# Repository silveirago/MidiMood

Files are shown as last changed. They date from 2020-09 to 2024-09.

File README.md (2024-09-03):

# MidiMood

For a detailed tutorial, visit: 

- Making Music with Arduino: https://go.musiconerd.com/making-music-with-arduino
- Curso Fazendo Música com Arduino em Português: https://go.musiconerd.com/curso-completo
- Build process video: https://youtu.be/aLhOO-UiMg4

This repository contains the code for a custom MIDI controller project called MidiMood, built using an ATmega32U4 microcontroller (or similar). The project is designed to handle potentiometers, buttons, and other controls to send MIDI messages via USB, BLE, or standard MIDI protocols.

## Table of Contents

- [Overview](#overview)
- [Features](#features)
- [Files Description](#files-description)
- [Setup Instructions](#setup-instructions)
- [Dependencies](#dependencies)
- [Usage](#usage)
- [License](#license)

## Overview

MidiMood is a comprehensive MIDI controller implementation that supports various input methods (buttons, potentiometers, encoders) and output methods (USB MIDI, BLE MIDI). The controller is designed to be highly customizable, supporting multiple microcontroller platforms including ATmega32U4, ATmega328, and Teensy.

## Features

- **USB MIDI Support**: Send and receive MIDI messages over USB.
- **BLE MIDI Support**: Use Bluetooth Low Energy (BLE) for wireless MIDI communication.
- **Potentiometer and Button Handling**: Capture input from potentiometers and buttons and convert them into MIDI messages.
- **Multiplexer Support**: Extend the number of inputs using multiplexers.
- **Debugging Support**: Debugging messages can be enabled via serial communication.
- **Multi-platform**: Supports ATmega32U4, ATmega328, and Teensy microcontrollers.

## Files Description

- **_MidiMood.ino**: The main Arduino sketch that initializes the MIDI controller and runs the main loop.
- **A_POTENTIOMETERS.ino**: Contains the logic for reading potentiometer values and converting them into MIDI Control Change messages.
- **B_BUTTONS.ino**: Handles the button inputs, converting them into MIDI Note On/Off or Control Change messages.
- **FUNCTIONS.ino**: Helper functions used throughout the project, including handling MIDI messages and other utility functions.
- **LOOP.ino**: The main loop where the program checks for inputs and sends out MIDI messages.
- **MACKIE.h**: Defines constants for Mackie Control Universal (MCU) protocol, used for controlling DAWs.
- **Z_ATMEGA32U4.ino**: Microcontroller-specific setup code for ATmega32U4-based boards.
- **Z_SETUP.ino**: General setup code, initializing pins, and configuring input/output modes.

## Material

* Arduino Pro Micro: https://amzn.to/2Vcz3Nz
* Wires: https://amzn.to/2xugvPF
* Bare Copper Wire (optional) 18-24-gauge: https://amzn.to/2FVuDpe
* 26 Rotary potentiometer b10k: https://amzn.to/3ckRKUY
* 26 Knobs
* Spacers M3 35mm: https://amzn.to/2z15BkN
* M3 screws: https://amzn.to/2RHtfJw
* Multiplexer CD4067: https://amzn.to/303jJVe
* 11 Toggle switch: https://amzn.to/3hDmORR
* 1 led
* 1 led support
* 1 resistor 1k ohm

## Setup Instructions

### 1. Clone the Repository

```bash
git clone https://github.com/yourusername/midi-controller-project.git
cd midi-controller-project
```

### 2. Install Arduino IDE

Make sure you have the Arduino IDE installed on your computer. You can download it from the [official website](https://www.arduino.cc/en/software).

### 3. Open the Project

Open the `_MidiMood.ino` file in the Arduino IDE. This file serves as the entry point to the project.

### 4. Select Your Board

In the Arduino IDE, select the appropriate board based on your microcontroller:
- For ATmega32U4 boards (e.g., Arduino Leonardo), select **Arduino Leonardo**.
- For ATmega328 boards (e.g., Arduino Uno), select **Arduino Uno**.
- For Teensy boards, select the correct Teensy model.

### 5. Upload the Code

Connect your microcontroller to your computer via USB and upload the code using the **Upload** button in the Arduino IDE.

## Dependencies

- **ResponsiveAnalogRead**: Library for smoothing analog readings from potentiometers.
- **MIDI Library**: To handle MIDI communication over USB and serial.
- **BLE MIDI**: For Bluetooth MIDI communication (if using BLE).

You can install these libraries using the Arduino Library Manager.

## Usage

Once the code is uploaded, your MIDI controller will be recognized by your computer or mobile device as a MIDI device. You can start using it to send MIDI messages to your DAW or other MIDI-compatible software.

### Debugging

If you want to see debugging messages, enable the `DEBUG` flag in the code. This will allow you to monitor the MIDI messages and other details via the serial monitor in the Arduino IDE.

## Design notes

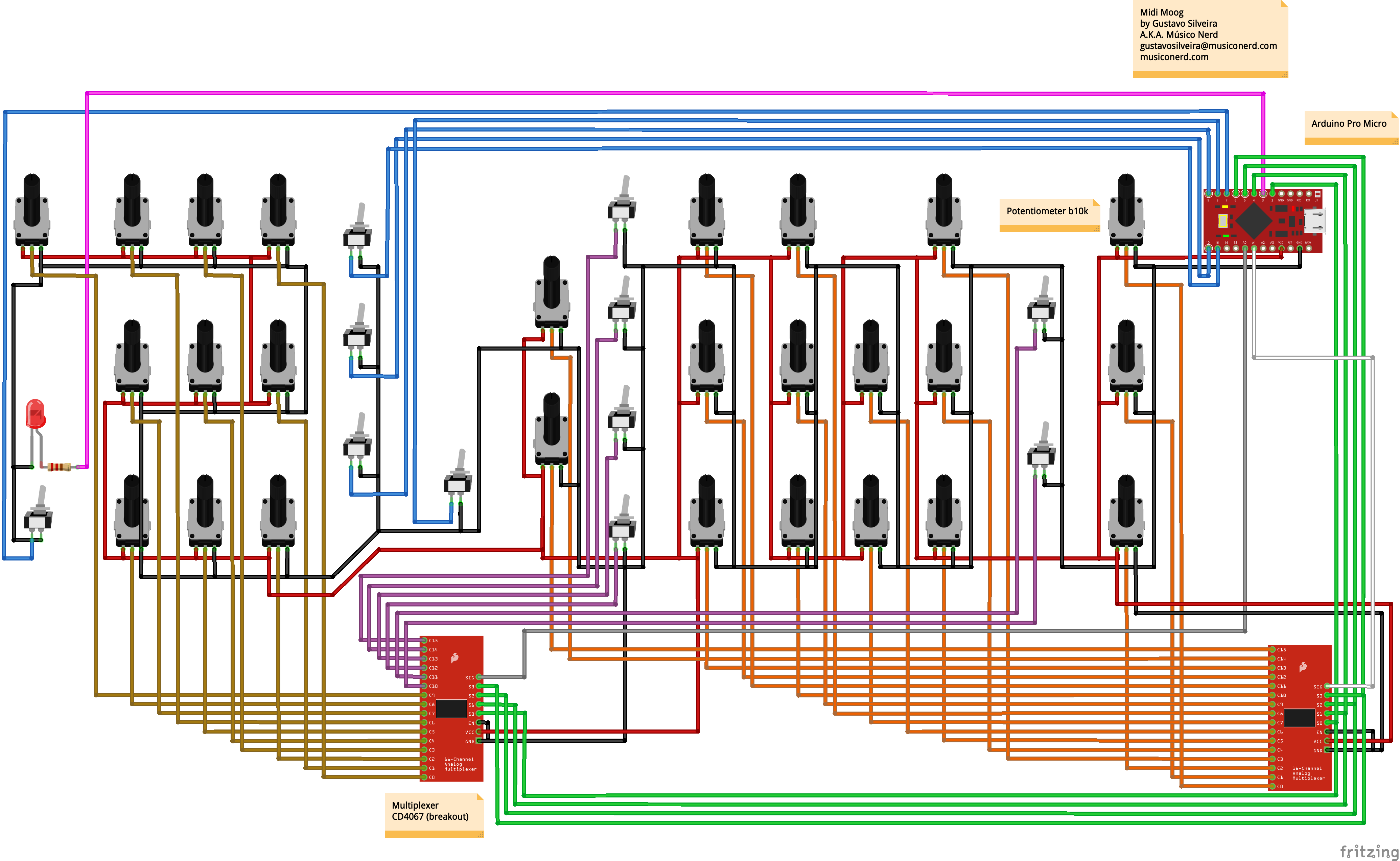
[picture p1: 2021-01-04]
Schematics/MidiMood schematic.png

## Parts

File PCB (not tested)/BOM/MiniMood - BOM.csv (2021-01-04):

Comment | Designator | Footprint | LCSC Part Number
CD74HC4067M | 4067_1,4067_2 | Package_SO:SOIC-24W_7.5x15.4mm_P1.27mm | C496123
100nF | C1,C2 | Capacitor_SMD:C_0603_1608Metric | C14663
220OHMS | R1 | Resistor_SMD:R_0603_1608Metric_Pad0.98x0.95mm_HandSolder | C21189

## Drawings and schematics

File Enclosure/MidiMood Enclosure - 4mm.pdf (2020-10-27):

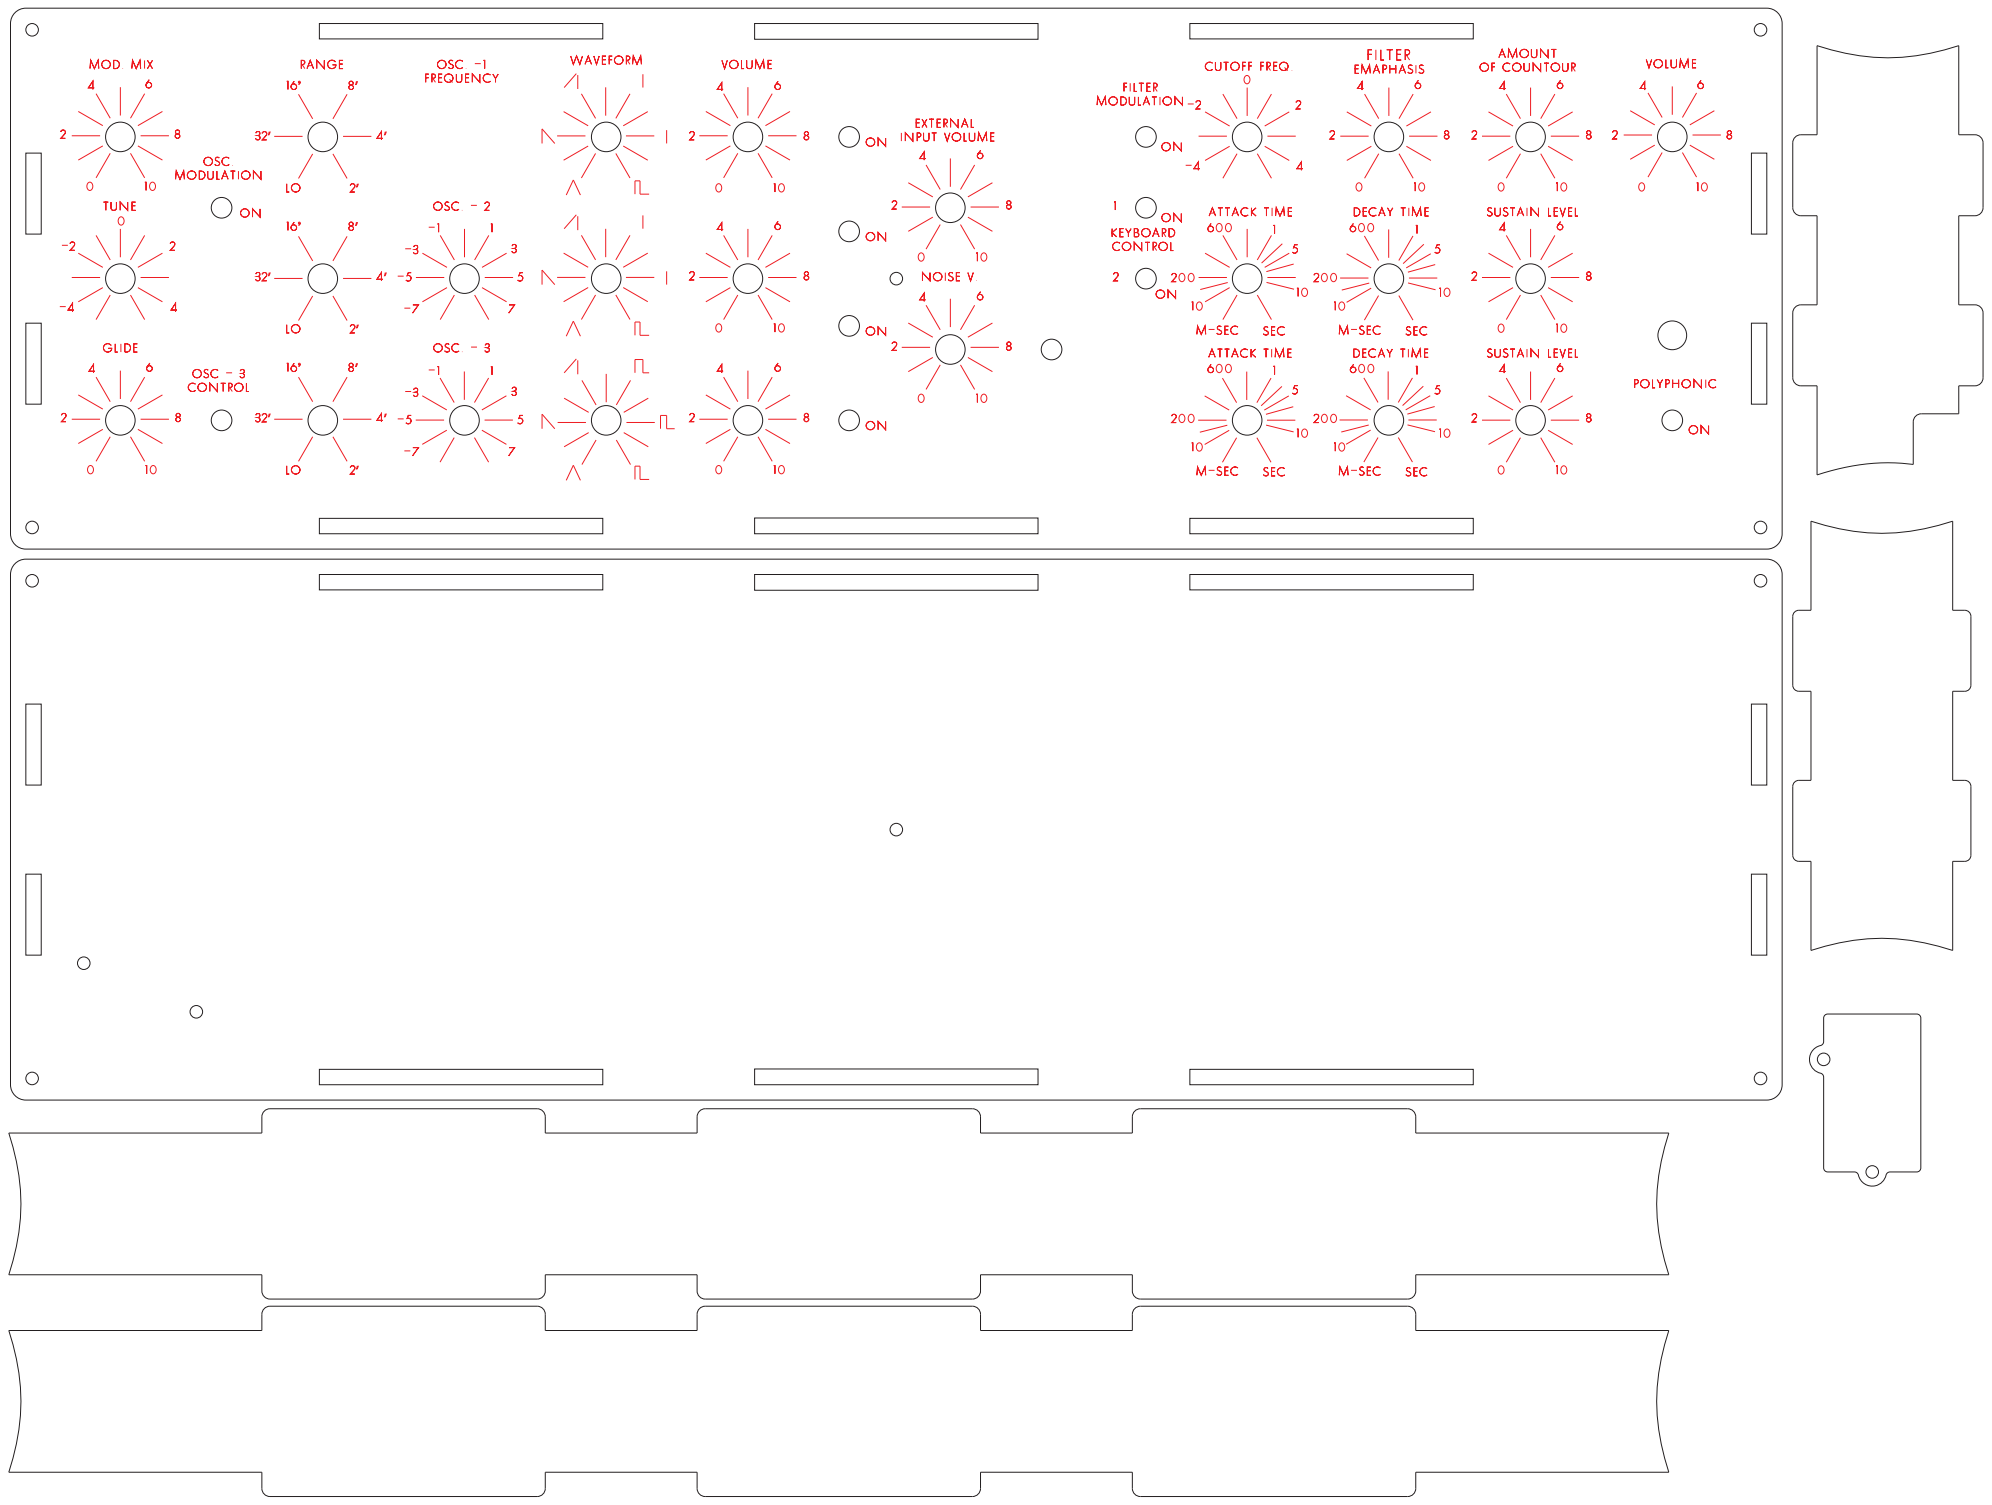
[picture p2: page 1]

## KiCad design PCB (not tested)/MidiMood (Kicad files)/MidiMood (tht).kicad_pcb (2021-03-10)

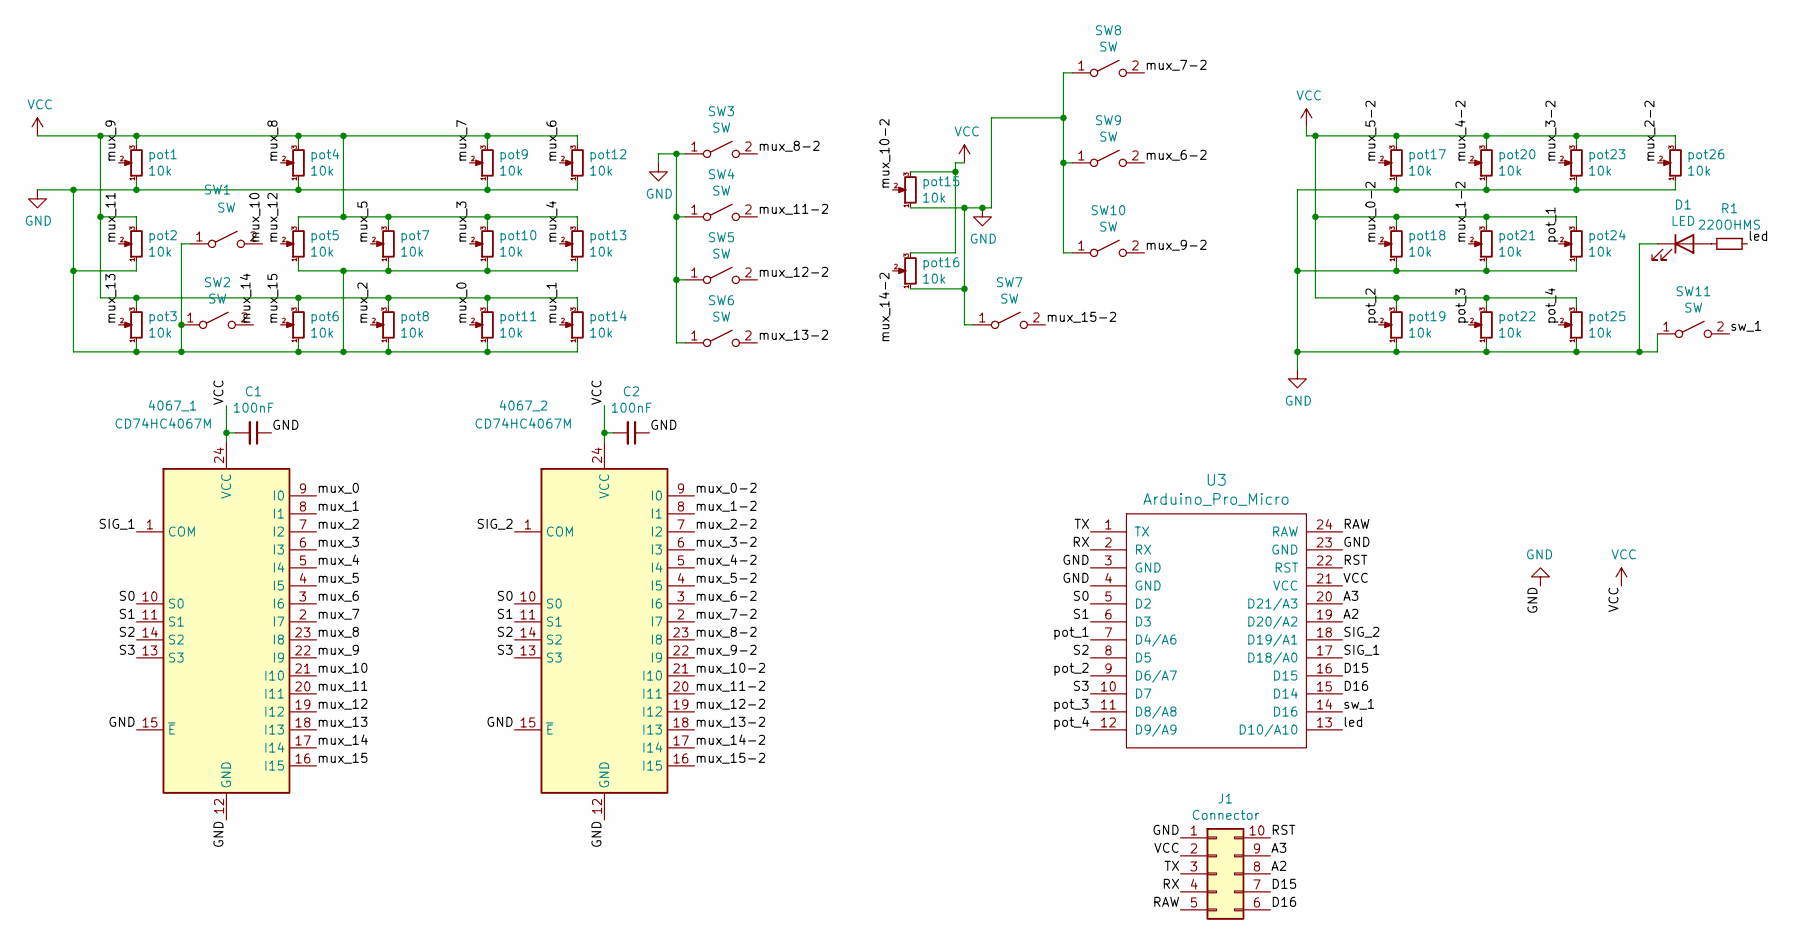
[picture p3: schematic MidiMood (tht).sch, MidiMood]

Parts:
4067_1, 4067_2: CD74HC4067M; SOIC-24W_7.5x15.4mm_P1.27mm; LCSC Part Number C496123
C1, C2: 100nF; C_Disc_D3.0mm_W1.6mm_P2.50mm; LCSC Part Number C14663
D1: LED; LED_D5.0mm
J1: Connector; PinHeader_2x05_P2.54mm_Vertical
R1: 220OHMS; R_Axial_DIN0204_L3.6mm_D1.6mm_P5.08mm_Horizontal; LCSC Part Number C21189
SW1, SW2, SW3, SW4, SW5, SW6, SW7, SW8, SW9, SW10, SW11: SW; Toggle switch small
U3: Arduino_Pro_Micro; ProMicro
pot1, pot2, pot3, pot4, pot5, pot6, pot7, pot8, pot9, pot10, pot11, pot12, pot13, pot14, pot15, pot16, pot17, pot18, pot19, pot20, pot21, pot22, pot23, pot24, pot25, pot26: 10k; Potentiometer_Alpha_RD901F-40-00D_Single_Vertical_CircularH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; LCSC RK09D1130C3C

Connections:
/A2: J1.8, U3.19 (D20/A2)
/A3: J1.9, U3.20 (D21/A3)
/D15: J1.7, U3.16 (D15)
/D16: J1.6, U3.15 (D14)
/RAW: J1.5, U3.24 (RAW)
/RST: J1.10, U3.22 (RST)
/RX: J1.4, U3.2 (RX)
/S0: 4067_1.10 (S0), 4067_2.10 (S0), U3.5 (D2)
/S1: 4067_1.11 (S1), 4067_2.11 (S1), U3.6 (D3)
/S2: 4067_1.14 (S2), 4067_2.14 (S2), U3.8 (D5)
/S3: 4067_1.13 (S3), 4067_2.13 (S3), U3.10 (D7)
/SIG_1: 4067_1.1 (COM), U3.17 (D18/A0)
/SIG_2: 4067_2.1 (COM), U3.18 (D19/A1)
/TX: J1.3, U3.1 (TX)
/led: R1.1, U3.13 (D10/A10)
/mux_0: 4067_1.9 (I0), pot11.2
/mux_0-2: 4067_2.9 (I0), pot18.2
/mux_1: 4067_1.8 (I1), pot14.2
/mux_1-2: 4067_2.8 (I1), pot21.2
/mux_2: 4067_1.7 (I2), pot8.2
/mux_2-2: 4067_2.7 (I2), pot26.2
/mux_3: 4067_1.6 (I3), pot10.2
/mux_3-2: 4067_2.6 (I3), pot23.2
/mux_4: 4067_1.5 (I4), pot13.2
/mux_4-2: 4067_2.5 (I4), pot20.2
/mux_5: 4067_1.4 (I5), pot7.2
/mux_5-2: 4067_2.4 (I5), pot17.2
/mux_6: 4067_1.3 (I6), pot12.2
/mux_6-2: 4067_2.3 (I6), SW9.2 (B)
/mux_7: 4067_1.2 (I7), pot9.2
/mux_7-2: 4067_2.2 (I7), SW8.2 (B)
/mux_8: 4067_1.23 (I8), pot4.2
/mux_8-2: 4067_2.23 (I8), SW3.2 (B)
/mux_9: 4067_1.22 (I9), pot1.2
/mux_9-2: 4067_2.22 (I9), SW10.2 (B)
/mux_10: 4067_1.21 (I10), SW1.2 (B)
/mux_10-2: 4067_2.21 (I10), pot15.2
/mux_11: 4067_1.20 (I11), pot2.2
/mux_11-2: 4067_2.20 (I11), SW4.2 (B)
/mux_12: 4067_1.19 (I12), pot5.2
/mux_12-2: 4067_2.19 (I12), SW5.2 (B)
/mux_13: 4067_1.18 (I13), pot3.2
/mux_13-2: 4067_2.18 (I13), SW6.2 (B)
/mux_14: 4067_1.17 (I14), SW2.2 (B)
/mux_14-2: 4067_2.17 (I14), pot16.2
/mux_15: 4067_1.16 (I15), pot6.2
/mux_15-2: 4067_2.16 (I15), SW7.2 (B)
/pot_1: U3.7 (D4/A6), pot24.2
/pot_2: U3.9 (D6/A7), pot19.2
/pot_3: U3.11 (D8/A8), pot22.2
/pot_4: U3.12 (D9/A9), pot25.2
/sw_1: SW11.2 (B), U3.14 (D16)
GND: 4067_1.12 (GND), 4067_1.15 (~E), 4067_2.12 (GND), 4067_2.15 (~E), C1.1, C2.1, D1.1 (K), J1.1, SW1.1 (A), SW2.1 (A), SW3.1 (A), SW4.1 (A), SW5.1 (A), SW6.1 (A), SW7.1 (A), SW8.1 (A), SW9.1 (A), SW10.1 (A), SW11.1 (A), U3.3 (GND), U3.4 (GND), U3.23 (GND), pot1.1, pot2.1, pot3.1, pot4.1, pot5.1, pot6.1, pot7.1, pot8.1, pot9.1, pot10.1, pot11.1, pot12.1, pot13.1, pot14.1, pot15.1, pot16.1, pot17.1, pot18.1, pot19.1, pot20.1, pot21.1, pot22.1, pot23.1, pot24.1, pot25.1, pot26.1
unnamed: D1.2 (A), R1.2
VCC: 4067_1.24 (VCC), 4067_2.24 (VCC), C1.2, C2.2, J1.2, U3.21 (VCC), pot1.3, pot2.3, pot3.3, pot4.3, pot5.3, pot6.3, pot7.3, pot8.3, pot9.3, pot10.3, pot11.3, pot12.3, pot13.3, pot14.3, pot15.3, pot16.3, pot17.3, pot18.3, pot19.3, pot20.3, pot21.3, pot22.3, pot23.3, pot24.3, pot25.3, pot26.3

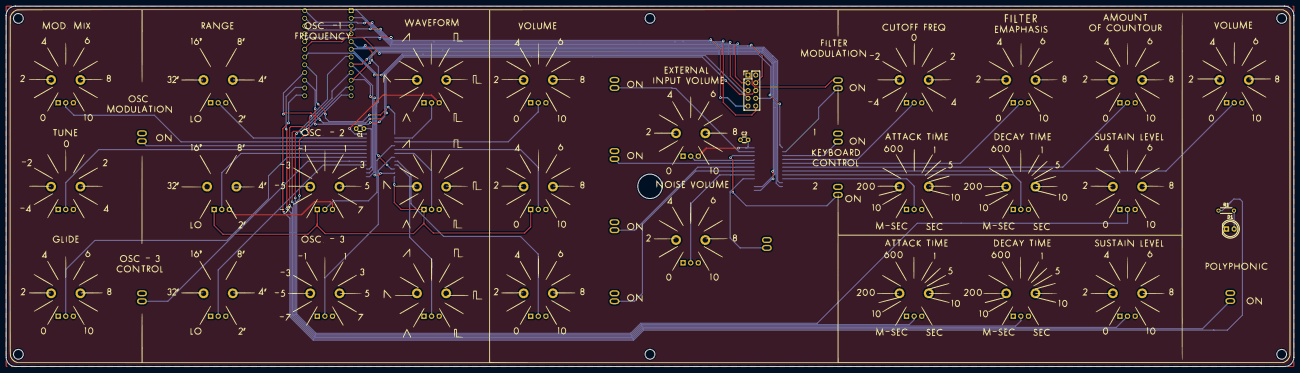
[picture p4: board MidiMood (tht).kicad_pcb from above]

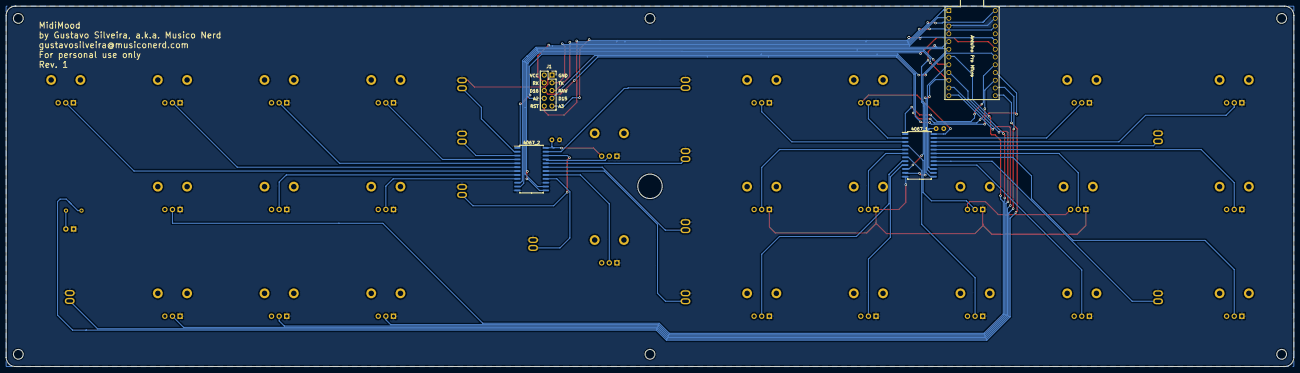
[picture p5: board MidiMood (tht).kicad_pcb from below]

Board: 2 copper layers, 422.4 x 118.2 mm, 45 parts (3 on the bottom side), 55 nets.

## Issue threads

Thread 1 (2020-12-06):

VCC and Ground Schematic Issue

jamesdesantiago, 2020-12-06:
I built the Midi Controller and it works! However, I noticed that in the schematic VCC and GRND aren't connected for the polyphonic toggle switch side of the circuit. Also, I'm having an issue with the Amount of Contour potentiometer. I'm analyzing the signal and it seems to be working but I can't assign it to anything in Ableton Live. Do you know why that is?

silveirago, 2020-12-11:
Hi sir, I just checked the schematics and it seems everything is connected
to the ground, even the toggle switches, they all have a common ground.
However, the toggle switches don't require VCC, only a digital pin (or
multiplexer). You should be able to map it on Ableton Live like any other
MIDI controller. It's hard to know what it could be from here... :/

Em dom., 6 de dez. de 2020 às 15:44, jamesdesantiago <
notifications@github.com> escreveu:

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

--
Gustavo Silveira
Composer / Multimedia Artist
www.gustavosilveira.net

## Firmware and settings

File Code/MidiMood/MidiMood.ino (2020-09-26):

/*
  Made by Gustavo Silveira, 2019.
  - This Sketch reads the Arduino's digital and analog ports and send midi notes and midi control change
  - It can use many multiplexers

  http://www.musiconerd.com
  http://www.youtube.com/musiconerd
  http://facebook.com/musiconerdmusiconerd
  http://instagram.com/musiconerd/
  http://www.gustavosilveira.net
  gustavosilveira@musiconerd.com

  If you are using for anything that's not for personal use don't forget to give credit.

  PS: Just change the value that has a comment like " //* "

*/

/////////////////////////////////////////////
// Choosing your board
// Define your board, choose:
// "ATMEGA328" if using ATmega328 - Uno, Mega, Nano...
// "ATMEGA32U4" if using with ATmega32U4 - Micro, Pro Micro, Leonardo...
// "TEENSY" if using a Teensy board
// "DEBUG" if you just want to debug the code in the serial monitor
// you don't need to comment or uncomment any MIDI library below after you define your board

#define ATMEGA32U4 1//* put here the uC you are using, like in the lines above followed by "1", like "ATMEGA328 1", "DEBUG 1", etc.

/////////////////////////////////////////////
// Are you using a multiplexer?
#define USING_MUX 1 //* comment if not using a multiplexer, uncomment if using it.

/////////////////////////////////////////////
// Are you using encoders?
// #define USING_ENCODER 1 //* comment if not using encoders, uncomment if using it.

/////////////////////////////////////////////
// LIBRARIES
// -- Defines the MIDI library -- //

// if using with ATmega328 - Uno, Mega, Nano...
#ifdef ATMEGA328
#include <MIDI.h>
//MIDI_CREATE_DEFAULT_INSTANCE();

// if using with ATmega32U4 - Micro, Pro Micro, Leonardo...
#elif ATMEGA32U4
#include "MIDIUSB.h"

#endif
// ---- //

//////////////////////
// Add this lib if using a cd4067 multiplexer
#ifdef USING_MUX
#include <Multiplexer4067.h> // Multiplexer CD4067 library >> https://github.com/sumotoy/Multiplexer4067
#endif

//////////////////////
// Threads
#include <Thread.h> // Threads library >> https://github.com/ivanseidel/ArduinoThread
#include <ThreadController.h> // Same as above

//////////////////////
// Encoder
#ifdef USING_ENCODER
// In the downloads manager download the Encoder lib from Paul Stoffregen (it comes with the Teensy)
#include <Encoder.h>  // makes all the work for you on reading the encoder
#endif

///////////////////////////////////////////
// MULTIPLEXERS
#ifdef USING_MUX

#define N_MUX 2 //* number of multiplexers
//* Define s0, s1, s2, s3, and x pins
#define s0 2
#define s1 4
#define s2 5
#define s3 6
#define x1 A0 // analog pin of the first mux
#define x2 A1 // analog pin of the second mux...
// add more #define and the x number if you need

// Initializes the multiplexer
Multiplexer4067 mux[N_MUX] = {
  Multiplexer4067(s0, s1, s2, s3, x2), //*
  Multiplexer4067(s0, s1, s2, s3, x1) //*
  // ...
};

#endif

/////////////////////////////////////////////
// BUTTONS
const int N_BUTTONS = 6 + 5; //*  total numbers of buttons. Number of buttons in the Arduino + number of buttons on multiplexer 1 + number of buttons on multiplexer 2...
const int N_BUTTONS_ARDUINO = 5; //* number of buttons connected straight to the Arduino (in order)
const int BUTTON_ARDUINO_PIN[N_BUTTONS] = {7, 8, 9, 10, 16}; //* pins of each button connected straight to the Arduino

//#define USING_CUSTOM_NN 1 //* comment if not using CUSTOM NOTE NUMBERS (scales), uncomment if using it.
#ifdef USING_CUSTOM_NN
int BUTTON_NN[N_BUTTONS] = {15, 20}; //* Add the NOTE NUMBER of each button/switch you want
#endif

#define USING_BUTTON_CC_N 1 //* comment if not using BUTTON CC, uncomment if using it.
#ifdef USING_BUTTON_CC_N // if using button with CC
int BUTTON_CC_N[N_BUTTONS] = {80, 81, 82, 83, 84, 85, 86, 87, 88, 89, 90}; //* Add the CC NUMBER of each button/switch you want
#endif

//#define USING_TOGGLE 1 //* comment if not using BUTTON TOGGLE mode, uncomment if using it.
// With toggle mode on, when you press the button once it sends a note on, when you press it again it sends a note off

#ifdef USING_MUX // Fill if you are using mux, otherwise just leave it
const int N_BUTTONS_PER_MUX[N_MUX] = {0, 6}; //* number of buttons in each mux (in order)
const int BUTTON_MUX_PIN[N_MUX][16] = { //* pin of each button of each mux in order
{}, //* pins of the first mux
{10, 11, 12, 13, 14, 15} //* pins of the second
// ...
};
#endif

int buttonMuxThreshold = 500;

int buttonCState[N_BUTTONS] = {0};        // stores the button current value
int buttonPState[N_BUTTONS] = {0};        // stores the button previous value

//#define pin13 1 // uncomment if you are using pin 13 (pin with led), or comment the line if it is not
byte pin13index = 12; //* put the index of the pin 13 of the buttonPin[] array if you are using, if not, comment

// debounce
unsigned long lastDebounceTime[N_BUTTONS] = {0};  // the last time the output pin was toggled
unsigned long debounceDelay = 5;    //* the debounce time; increase if the output flickers

// velocity
byte velocity[N_BUTTONS] = {127};

/////////////////////////////////////////////
// POTENTIOMETERS
const int N_POTS = 16 + 10 + 0; //* total numbers of pots (slide & rotary). Number of pots in the Arduino + number of pots on multiplexer 1 + number of pots on multiplexer 2...
const int N_POTS_ARDUINO = 0; //* number of pots connected straight to the Arduino
const int POT_ARDUINO_PIN[N_POTS_ARDUINO] = {}; //* pins of each pot connected straight to the Arduino

#define USING_CUSTOM_CC_N 1 //* comment if not using CUSTOM CC NUMBERS, uncomment if using it.
#ifdef USING_CUSTOM_CC_N
int POT_CC_N[N_POTS] = {14, 15, 5, 16, 17, 18, 19, 20, 21, 22, 23, 24, 25, 26, 27, 28, 74, 29, 73, 71, 30, 31, 32, 33, 34, 7}; // Add the CC NUMBER of each pot you want
#endif

#ifdef USING_MUX
const int N_POTS_PER_MUX[N_MUX] = {16, 10}; //* number of pots in each multiplexer (in order)
const int POT_MUX_PIN[N_MUX][16] = { //* pins of each pot of each mux in the order you want them to be

{0, 1, 2, 3, 4, 5, 6, 7, 8, 9, 10, 11, 12, 13, 14, 15}, // pins of the first mux
{0, 1, 2, 3, 4, 5, 6, 7, 8, 9, 10} // pins of the second mux
// ...
};
#endif

int potCState[N_POTS] = {0}; // Current state of the pot
int potPState[N_POTS] = {0}; // Previous state of the pot
int potVar = 0; // Difference between the current and previous state of the pot

int potMidiCState[N_POTS] = {0}; // Current state of the midi value
int potMidiPState[N_POTS] = {0}; // Previous state of the midi value

const int TIMEOUT = 300; //* Amount of time the potentiometer will be read after it exceeds the varThreshold
const int varThreshold = 10; //* Threshold for the potentiometer signal variation
boolean potMoving = true; // If the potentiometer is moving
unsigned long PTime[N_POTS] = {0}; // Previously stored time
unsigned long timer[N_POTS] = {0}; // Stores the time that has elapsed since the timer was reset

/////////////////////////////////////////////
// ENCODERS
#ifdef USING_ENCODER
// You can add as many encoders you want separated in many encoderChannels you want
//#define TRAKTOR 1 // uncomment if using with traktor, comment if not
const int N_ENCODERS = 2; //* number of encoders
const int N_ENCODER_CHANNELS = 1; //* number of encoderChannels
const int N_ENCODER_PINS = N_ENCODERS * 2; //number of pins used by the encoders

Encoder encoder[N_ENCODERS] = {{9, 8}, {11, 10}}; // the two pins of each encoder (backwards) -  Use pins with Interrupts!

int encoderMinVal = 0; //* encoder minimum value
int encoderMaxVal = 127; //* encoder maximum value

int preset[N_ENCODER_CHANNELS][N_ENCODERS] = { //stores presets to start your encoders
  {64, 64},
};

int lastEncoderValue[N_ENCODER_CHANNELS][N_ENCODERS] = {127};
int encoderValue[N_ENCODER_CHANNELS][N_ENCODERS] = {127};

// for the encoder Channels - Used for different banks
int encoderChannel = 0;
int lastEncoderChannel = 0;

#endif
/////////////////////////////////////////////

byte MIDI_CH = 1; //* MIDI channel to be used
byte NOTE = 36; //* Lowest NOTE to be used - if not using custom NOTE NUMBER
byte CC = 1; //* Lowest MIDI CC to be used - if not using custom CC NUMBER

/////////////////////////////////////////////
// THREADS
// This libs create a "fake" thread. This means you can make something happen every x milisseconds
// We can use that to read something in an interval, instead of reading it every single loop
// In this case we'll read the potentiometers in a thread, making the reading of the buttons faster
ThreadController cpu; //thread master, where the other threads will be added
Thread threadPotentiometers; // thread to control the pots

/////////////////////////////////////////////
// LED
byte ledPin = 3;

void setup() {

  // Baud Rate
  // use if using with ATmega328 (uno, mega, nano...)
  // 31250 for MIDI class compliant | 115200 for Hairless MIDI
  Serial.begin(115200); //*

#ifdef DEBUG
Serial.println("Debug mode");
Serial.println();
#endif

  // Buttons
  // Initialize buttons with pull up resistors
  for (int i = 0; i < N_BUTTONS_ARDUINO; i++) {
    pinMode(BUTTON_ARDUINO_PIN[i], INPUT_PULLUP);
  }

#ifdef pin13 // Initialize pin 13 as an input
pinMode(BUTTON_ARDUINO_PIN[pin13index], INPUT);
#endif

  /////////////////////////////////////////////
  // Multiplexers

#ifdef USING_MUX

  // Initialize the multiplexers
  for (int i = 0; i < N_MUX; i++) {
    mux[i].begin();
  }
  //* Set each X pin as input_pullup (avoid floating behavior)
  pinMode(x1, INPUT_PULLUP);
  pinMode(x2, INPUT_PULLUP);

#endif

  /////////////////////////////////////////////
  // Threads
  threadPotentiometers.setInterval(10); // every how many millisiconds
  threadPotentiometers.onRun(potentiometers); // the function that will be added to the thread
  cpu.add(&threadPotentiometers); // add every thread here

  /////////////////////////////////////////////
  // Encoders
#ifdef USING_ENCODER

  for (int i = 0; i < N_ENCODERS; i++) { // if you want to start with a certain value use presets
    encoder[i].write(preset[0][i]);
  }

  for (int z = 0; z < N_ENCODER_CHANNELS; z++) {
    for (int i = 0; i < N_ENCODERS; i++) {
      lastEncoderValue[z][i] = preset[z][i];
      encoderValue[z][i] = preset[z][i];
    }
  }

#endif
/////////////////////////////////////////////

  /////////////////////////////////////////////
  // LED
  pinMode(ledPin, OUTPUT);
  analogWrite(ledPin, 100);
}

void loop() {

  cpu.run(); // for threads
  buttons();

#ifdef USING_ENCODER
encoders();
#endif

}

/////////////////////////////////////////////
// BUTTONS
void buttons() {

  // read pins from arduino
  for (int i = 0; i < N_BUTTONS_ARDUINO; i++) {
    buttonCState[i] = !(digitalRead(BUTTON_ARDUINO_PIN[i]));
  }

#ifdef USING_MUX

  // It will happen if you are using MUX
  int nButtonsPerMuxSum = N_BUTTONS_ARDUINO; // offsets the buttonCState at every mux reading

  // read the pins from every mux
  for (int j = 0; j < N_MUX; j++) {
    for (int i = 0; i < N_BUTTONS_PER_MUX[j]; i++) {
      buttonCState[i + nButtonsPerMuxSum] = mux[j].readChannel(BUTTON_MUX_PIN[j][i]);
      // Scale values to 0-1
      if (buttonCState[i + nButtonsPerMuxSum] > buttonMuxThreshold) {
        buttonCState[i + nButtonsPerMuxSum] = LOW;
      }
      else {
        buttonCState[i + nButtonsPerMuxSum] = HIGH;
      }
    }
    nButtonsPerMuxSum += N_BUTTONS_PER_MUX[j];
  }
#endif

  for (int i = 0; i < N_BUTTONS; i++) { // Read the buttons connected to the Arduino

#ifdef pin13

    // It will happen if you are using pin 13
    if (i == pin13index) {
      buttonCState[i] = !buttonCState[i]; // inverts the pin 13 because it has a pull down resistor instead of a pull up
    }
#endif

    if ((millis() - lastDebounceTime[i]) > debounceDelay) {

      if (buttonPState[i] != buttonCState[i]) {
        lastDebounceTime[i] = millis();

        if (buttonCState[i] == LOW) {

#ifndef USING_TOGGLE // if NOT using button toggle mode

          velocity[i] = 127; // if button is pressed velocity is 127
#else

          velocity[i] = !velocity[i] * 127; // changes the velocity between 0 and 127 each time one press a button
#endif

        }
        else {

#ifndef USING_TOGGLE // if NOT using button toggle mode

          velocity[i] = 0; // if button is released velocity is 0
#endif
}


          // Sends the MIDI NOTE ON accordingly to the chosen board

#ifdef USING_TOGGLE

          if (buttonCState[i] == LOW) { // only when button is pressed
#endif

            /////////////////////////////////////////////
#ifdef ATMEGA328

            // it will happen if using with ATmega328 (uno, mega, nano...)

#ifndef USING_BUTTON_CC_N // if NOT using button CC

#ifdef USING_CUSTOM_NN

            // if using custom NOTE numbers
            MIDI.sendNoteOn(BUTTON_NN[i], velocity[i], MIDI_CH); // note, velocity, channel
#else

            // if not using custom NOTE numbers
            MIDI.sendNoteOn(NOTE + i, velocity[i], MIDI_CH); // note, velocity, channel
#endif

#else // if USING button CC

           // if (buttonCState[i] == LOW) { // only sends note on when button is pressed, nothing when released
              MIDI.sendControlChange(BUTTON_CC_N[i], velocity[i], MIDI_CH); // note, velocity, channel
            //}
#endif

            /////////////////////////////////////////////
#elif ATMEGA32U4

            // it will happen if using with ATmega32U4 (micro, pro micro, leonardo...)

#ifndef USING_BUTTON_CC_N // if NOT using button CC

#ifdef USING_CUSTOM_NN

            // if using custom NOTE numbers
            noteOn(MIDI_CH, BUTTON_NN[i], velocity[i]);  // channel, note, velocity
            MidiUSB.flush();
#else

            // if not using custom NOTE
            noteOn(MIDI_CH, NOTE + i, velocity[i]);  // channel, note, velocity
            MidiUSB.flush();
#endif

#else // if USING button CC

           // if (velocity[i] > 0) { // only sends note on when button is pressed, nothing when released
              controlChange(MIDI_CH, BUTTON_CC_N[i], velocity[i]); //  (channel, CC number,  CC value)
              MidiUSB.flush();
            //}
#endif


            /////////////////////////////////////////////
#elif TEENSY
//do usbMIDI.sendNoteOn if using with Teensy

#ifndef USING_BUTTON_CC_N // if NOT using button CC

#ifdef USING_CUSTOM_NN

            // if using custom NOTE numbers
            usbMIDI.sendNoteOn(BUTTON_NN[i], velocity[i], MIDI_CH); // note, velocity, channel
#else

            // if not using custom NOTE
            usbMIDI.sendNoteOn(NOTE + i, velocity[i], MIDI_CH); // note, velocity, channel
#endif

#else // if USING button CC

            //if (velocity[i] > 0) { // only sends note on when button is pressed, nothing when released
              usbMIDI.sendControlChange(BUTTON_CC_N[i], velocity[i], MIDI_CH); // CC number, CC value, midi channel
            //}
#endif

            /////////////////////////////////////////////
#elif DEBUG

#ifndef USING_BUTTON_CC_N // print if not using button cc number

            Serial.print("Button: ");
            Serial.print(i);
            Serial.print("  | ch: ");
            Serial.print(MIDI_CH);
            Serial.print("  | nn: ");

#ifdef USING_CUSTOM_NN

            Serial.print(BUTTON_NN[i]);
#else

            Serial.print(NOTE + i);
#endif

            Serial.print("  | velocity: ");
            Serial.println(velocity[i]);
#else

            Serial.print("Button: ");
            Serial.print(i);
            Serial.print("  | ch: ");
            Serial.print(MIDI_CH);
            Serial.print("  | cc: ");
            Serial.print(BUTTON_CC_N[i]);
            Serial.print("  | value: ");
            Serial.println(velocity[i]);
#endif

#endif

            /////////////////////////////////////////////

#ifdef USING_TOGGLE

          }
#endif

          buttonPState[i] = buttonCState[i];
        }

      }
    }
  }

  /////////////////////////////////////////////
  // POTENTIOMETERS
  void potentiometers() {

    // reads the pins from arduino
    for (int i = 0; i < N_POTS_ARDUINO; i++) {
      potCState[i] = analogRead(POT_ARDUINO_PIN[i]);
    }

#ifdef USING_MUX
//It will happen if using a mux
int nPotsPerMuxSum = N_POTS_ARDUINO; //offsets the buttonCState at every mux reading

    // reads the pins from every mux
    for (int j = 0; j < N_MUX; j++) {
      for (int i = 0; i < N_POTS_PER_MUX[j]; i++) {
        potCState[i + nPotsPerMuxSum] = mux[j].readChannel(POT_MUX_PIN[j][i]);
      }
      nPotsPerMuxSum += N_POTS_PER_MUX[j];
    }
#endif

    //Debug only
    //    for (int i = 0; i < nPots; i++) {
    //      Serial.print(potCState[i]); Serial.print(" ");
    //    }
    //    Serial.println();

    for (int i = 0; i < N_POTS; i++) { // Loops through all the potentiometers

      potMidiCState[i] = map(potCState[i], 0, 1023, 0, 127); // Maps the reading of the potCState to a value usable in midi

      potVar = abs(potCState[i] - potPState[i]); // Calculates the absolute value between the difference between the current and previous state of the pot

      if (potVar > varThreshold) { // Opens the gate if the potentiometer variation is greater than the threshold
        PTime[i] = millis(); // Stores the previous time
      }

      timer[i] = millis() - PTime[i]; // Resets the timer 11000 - 11000 = 0ms

      if (timer[i] < TIMEOUT) { // If the timer is less than the maximum allowed time it means that the potentiometer is still moving
        potMoving = true;
      }
      else {
        potMoving = false;
      }

      if (potMoving == true) { // If the potentiometer is still moving, send the change control
        if (potMidiPState[i] != potMidiCState[i]) {

          // Sends the MIDI CC accordingly to the chosen board
#ifdef ATMEGA328
// use if using with ATmega328 (uno, mega, nano...)

#ifdef USING_CUSTOM_CC_N
MIDI.sendControlChange(POT_CC_N[i], potMidiCState[i], MIDI_CH); // CC number, CC value, midi channel - custom cc
#else
MIDI.sendControlChange(CC + i, potMidiCState[i], MIDI_CH); // CC number, CC value, midi channel
#endif

#elif ATMEGA32U4
//use if using with ATmega32U4 (micro, pro micro, leonardo...)

#ifdef USING_CUSTOM_CC_N
controlChange(MIDI_CH, POT_CC_N[i], potMidiCState[i]); //  (channel, CC number,  CC value)
MidiUSB.flush();
#else
controlChange(MIDI_CH, CC + i, potMidiCState[i]); //  (channel, CC number,  CC value)
MidiUSB.flush();
#endif

#elif TEENSY
//do usbMIDI.sendControlChange if using with Teensy

#ifdef USING_CUSTOM_CC_N
usbMIDI.sendControlChange(POT_CC_N[i], potMidiCState[i], MIDI_CH); // CC number, CC value, midi channel
#else
usbMIDI.sendControlChange(CC + i, potMidiCState[i], MIDI_CH); // CC number, CC value, midi channel
#endif

#elif DEBUG
Serial.print("Pot: ");
Serial.print(i);
Serial.print("  |  ch: ");
Serial.print(MIDI_CH);
Serial.print("  |  cc: ");
#ifdef USING_CUSTOM_NN
Serial.print(POT_CC_N[i]);
#else
Serial.print(CC + i);
#endif
Serial.print("  |  value: ");
Serial.println(potMidiCState[i]);
#endif


          potPState[i] = potCState[i]; // Stores the current reading of the potentiometer to compare with the next
          potMidiPState[i] = potMidiCState[i];
        }
      }
    }
  }

  /////////////////////////////////////////////
  // ENCODERS
#ifdef USING_ENCODER

  void encoders() {

    for (int i = 0; i < N_ENCODERS; i++) {
      encoderValue[encoderChannel][i] = encoder[i].read(); // reads each encoder and stores the value
    }

    for (int i = 0; i < N_ENCODERS; i++) {

      if (encoderValue[encoderChannel][i] != lastEncoderValue[encoderChannel][i]) {

#ifdef TRAKTOR // to use with Traktor
if (encoderValue[encoderChannel][i] > lastEncoderValue[encoderChannel][i]) {
encoderValue[encoderChannel][i] = 127;
} else {
encoderValue[encoderChannel][i] = 0;
}
#endif

        clipEncoderValue(i, encoderMinVal, encoderMaxVal); // checks if it's greater than the max value or less than the min value

        // Sends the MIDI CC accordingly to the chosen board
#ifdef ATMEGA328
// if using with ATmega328 (uno, mega, nano...)
MIDI.sendControlChange(i, encoderValue[encoderChannel][i], encoderChannel);

#elif ATMEGA32U4
// if using with ATmega32U4 (micro, pro micro, leonardo...)
controlChange(i, encoderValue[encoderChannel][i], encoderChannel);
MidiUSB.flush();

#elif TEENSY
// if using with Teensy
usbMIDI.sendControlChange(i, encoderValue[encoderChannel][i], encoderChannel);

#elif DEBUG
Serial.print("encoder channel: "); Serial.print(encoderChannel); Serial.print("  ");
Serial.print("Encoder "); Serial.print(i); Serial.print(": ");
Serial.println(encoderValue[encoderChannel][i]);
#endif

        lastEncoderValue[encoderChannel][i] = encoderValue[encoderChannel][i];
      }
    }
  }


  ////////////////////////////////////////////
  // checks if it's greater than maximum value or less than then the minimum value
  void clipEncoderValue(int i, int minVal, int maxVal) {

    if (encoderValue[encoderChannel][i] > maxVal - 1) {
      encoderValue[encoderChannel][i] = maxVal;
      encoder[i].write(maxVal);
    }
    if (encoderValue[encoderChannel][i] < minVal + 1) {
      encoderValue[encoderChannel][i] = minVal;
      encoder[i].write(minVal);
    }
  }

#endif

  /////////////////////////////////////////////
  // if using with ATmega32U4 (micro, pro micro, leonardo...)
#ifdef ATMEGA32U4

  // Arduino (pro)micro midi functions MIDIUSB Library
  void noteOn(byte channel, byte pitch, byte velocity) {
    midiEventPacket_t noteOn = {0x09, 0x90 | channel, pitch, velocity};
    MidiUSB.sendMIDI(noteOn);
  }

  void noteOff(byte channel, byte pitch, byte velocity) {
    midiEventPacket_t noteOff = {0x08, 0x80 | channel, pitch, velocity};
    MidiUSB.sendMIDI(noteOff);
  }

  void controlChange(byte channel, byte control, byte value) {
    midiEventPacket_t event = {0x0B, 0xB0 | channel, control, value};
    MidiUSB.sendMIDI(event);
  }

#endif

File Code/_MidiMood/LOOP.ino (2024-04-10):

void loop() {

#ifdef ATMEGA32U4

  // it will read MIDI incoming messages if using ATMEGA32U4
  MIDIread();

#ifdef MIDI_DIN
  midi2.read();
#endif

#endif

#ifdef ATMEGA328
  MIDI.read();
#endif

#ifdef TEENSY

  // usbMIDI.read() needs to be called rapidly from loop().  When
  // each MIDI messages arrives, it return true.  The message must
  // be fully processed before usbMIDI.read() is called again.
  if (usbMIDI.read()) {
    processMIDI();
  }

#endif

  buttons();
  potentiometers();
}

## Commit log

2020-09-17 schematics added
    [MidiMood schematic.fzz]
2020-09-25 schematic updated. Some pins of the mux were missing.
    [MidiMood schematic.fzz]
2020-09-26 schematics updated
2020-10-27 enclosure laser cut design now fits Ponoko standarts
2021-01-04 schematic gnd and 5v fixed
    [MidiMood schematic.fzz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]
2021-01-04 enclosure measures fixed
2021-03-10 Kicad files added
    [MidiMood (tht).kicad_pcb, MidiMood (tht).sch]
2024-04-10 new code added
    [MidiMood (tht).kicad_pcb, MidiMood (tht).sch, MiniMood - BOM.csv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]
